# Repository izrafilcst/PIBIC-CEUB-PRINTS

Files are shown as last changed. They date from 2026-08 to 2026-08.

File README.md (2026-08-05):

# Tampa com encaixe para botões de arcade — PIBIC-CEUB

Modelagem de uma tampa em PETG com encaixe para dois botões de arcade,
derivada dos desenhos esquemáticos `botao-verde-desenho-esquematico.jpg` e
`botao-vermelho-desenho-esquematico.jpg`.

## Arquivos

| Arquivo | O que é |
|---|---|
| `desenho-tampa.svg` | Desenho técnico da tampa: distâncias entre botões, Ø dos furos, corte e **DETALHE B** do furo de fixação |
| `desenho-gabarito-passante.svg` | Desenho do gabarito de furo liso |
| `desenho-gabarito-roscado.svg` | Desenho do gabarito de rosca interna |
| `desenho-perfil-rosca.svg` | Perfil ISO 68-1 da M24 × 2 ampliado 18:1, com a memória de cálculo |
| `gabarito-passante.stl` | **Imprima primeiro.** 160 × 40 × 8 mm, 5 furos lisos |
| `gabarito-roscado.stl` | **Imprima junto.** 160 × 40 × 8 mm, 5 roscas M24 × 2 reais |
| `tampa-botoes.stl` / `.scad` | Tampa final, 209,30 × 108,50 × 4 mm, com os 2 furos M24 e os 6 furos de fixação rebaixados |
| `LISTA-DE-MATERIAIS.md` | **BOM completa** — botões, ferragens, fiação, solda, filamento, ferramentas |
| `desenho-caixa-painel.svg` | Painel dos botões do `.3mf` (Body1): 2 × Ø26, 9 × Ø10, círculos de furação |
| `desenho-caixa-corpo.svg` | Corpo do `.3mf` (Body2): parede, altura, 6 furos de inserto e o detalhe da interferência |
| `desenho-caixa-tampa.svg` | Tampa do `.3mf`: 6 furos rebaixados e detalhe 8:1 |
| `gerar_desenhos_3mf.py` | Gera os três acima **lendo a malha dos `.3mf`** — toda cota é medida, nenhuma digitada |
| `gerar_stl.py` | Gera os `.stl` (Python puro, sem dependências) |
| `gerar_desenhos.py` | Gera os `.svg` a partir das **mesmas** constantes de `gerar_stl.py` |
| `validar_stl.py` | Verifica estanqueidade, orientação, volume e perfil da rosca |

Os SVG abrem em qualquer navegador e estão em escala 1:1 em milímetros
(1 unidade SVG = 1 mm), então podem ser impressos em papel e medidos com régua.

> **Obsoletos:** `gabarito-tolerancia.scad` e `gabarito-tolerancia.stl` são da
> primeira versão (4 mm, 180 × 45). Foram substituídos pelo par
> passante/roscado de 8 mm. Pode apagar os dois — não imprima por engano.

---

## Cotas extraídas dos desenhos

### Botão verde — arcade 60 mm

| Cota | Valor (mm) |
|---|---|
| Rosca | M24 (P = 2) |
| Ø capa / bezel | 60,8 |
| Ø flange do corpo (apoia sobre o painel) | 37,7 |
| Espessura do flange | 4,4 |
| Altura acima do painel | 10,0 |
| Barril roscado abaixo do painel | 30,5 |
| Corpo do microswitch | 21,9 |
| Altura total | 62,4 |
| Anti-rotação | 2 × Ø3,3 |

**Verificação de consistência:** 10,0 + 30,5 + 21,9 = 62,4 ✔ — as cotas
fecham exatamente com a altura total, o que confirma a leitura do desenho.

### Botão vermelho — domo 100 mm

| Cota | Valor (mm) |
|---|---|
| Rosca | M24 × P2 |
| Ø domo externo | 98,5 |
| Ø anel interno | 87,8 |
| Altura acima do painel | 17,5 |
| Etapas do corpo | 6,5 / 21 / 10,5 / 3 |
| Anti-rotação | 2 × R3 |

### Consequência prática

Os dois botões usam **M24 × 2**, então o furo do painel é **idêntico** para
ambos — só muda o espaço livre ao redor. E o barril de 30,5 mm do verde
(o mais curto dos dois) deixa ~26 mm de rosca livre numa tampa de 4 mm,
folga mais que suficiente para a porca.

---

## Memória de cálculo

### 1. Distância entre os botões

`4 cm entre os botões` foi interpretado como **folga livre borda-a-borda**,
não centro-a-centro. Centro-a-centro de 40 mm é fisicamente impossível: só os
raios das capas somam 49,25 + 30,40 = **79,65 mm** — as capas se sobreporiam
em 39,65 mm antes mesmo de existir folga.

```
centro-a-centro = Ø_vermelho/2 + folga + Ø_verde/2
                = 98,5/2 + 40,00 + 60,8/2
                = 49,25  + 40,00 + 30,40
                = 119,65 mm
```

### 2. Tamanho da placa

```
largura = margem + Ø_verm/2 + 119,65 + Ø_verde/2 + margem
        = 5 + 49,25 + 119,65 + 30,40 + 5 = 209,30 mm
altura  = margem + Ø_verm + margem = 5 + 98,5 + 5 = 108,50 mm

x do furo vermelho = 5 + 49,25            =  54,25 mm
x do furo verde    = 54,25 + 119,65       = 173,90 mm
y de ambos         = 108,50 / 2           =  54,25 mm
```

`margem = 5` foi escolhida pela mesa da K1C: 209,30 numa mesa de 220 deixa
5,35 mm de cada lado em X — o suficiente para o skirt e para a sondagem de
nivelamento. Com `margem = 8` (o valor inicial) a peça ia a 215,30 e sobravam
2,35 mm por lado, o que não cabe. Acima de `margem = 7` o skirt não passa.

### 3. Perfil da rosca ISO 68-1 (M24 × 2)

Todos os valores vêm de duas constantes: `D = 24` e `P = 2`.

```
H  = P·√3/2 = 2 · 0,8660254 = 1,7320508 mm      (altura do triângulo gerador)
5H/8 = 1,0825318 mm                              (profundidade radial do filete)

D1 = D − 2·(5H/8) = 24 − 2,1650635 = 21,8349365 mm   → tabela ISO: 21,835 ✔
D2 = D − 0,649519·P = 24 − 1,299038 = 22,7009619 mm  → tabela ISO: 22,701 ✔
```

Decomposição de **um passo** ao longo do eixo, que é o que o gerador de malha
percorre:

```
plano da crista   P/4    = 0,500
flanco            5P/16  = 0,625
plano da raiz     P/8    = 0,250
flanco            5P/16  = 0,625
                  ─────────────
                  16P/16 = 2,000 = P   ✔ fecha exatamente
```

O comprimento axial do flanco sai do ângulo de 60° do perfil:

```
flanco = (5H/8) · tan30° = (5/8)·(P√3/2) · (1/√3) = 5P/16
```

Essa forma fechada importa: usando o literal arredondado `0,5412659·P` o
fechamento do passo errava por 2,6 × 10⁻⁸ mm e o teste de ângulo de flanco
falhava. Com `5P/16` o fechamento é exato em ponto flutuante binário
(P/4 + 5P/16 + P/8 + 5P/16 = P sem erro), e a validação passa.

No `desenho-perfil-rosca.svg` o triângulo gerador está desenhado com o **ápice
no meio do plano da crista**, a `H/4` além de D1, e os cantos da base a `H/8`
além de D — que é a truncagem da norma (`H − H/8 − H/4 = 5H/8`, batendo com
D1 = D − 2·5H/8). Por isso os flancos do triângulo caem exatamente sobre os
flancos do perfil.

### 4. Por que δ de 0,10 a 0,50

`δ` é a **folga radial** somada ao perfil ISO: desloca `Rmaj` e `Rmin` juntos
para fora, o que aumenta os dois diâmetros em `2δ` sem alterar o passo, o
ângulo de flanco nem a decomposição axial acima.

| δ | D maior | D1 menor | folga no Ø |
|---|---|---|---|
| 0,10 | 24,20 | 22,03 | +0,20 |
| 0,20 | 24,40 | 22,23 | +0,40 |
| 0,30 | 24,60 | 22,43 | +0,60 |
| 0,40 | 24,80 | 22,63 | +0,80 |
| 0,50 | 25,00 | 22,83 | +1,00 |

A faixa cobre de 0,20 a 1,00 mm no diâmetro porque é onde cai o erro típico de
FDM em PETG: 0,3–0,5 mm de fechamento por camada de parede, e uma rosca é
essencialmente uma sequência de paredes finas concêntricas, onde o efeito é
maior que num furo liso. Abaixo de δ = 0,10 a rosca sai travada; acima de
δ = 0,50 ela gira folgada e não segura o botão. O passo de 0,10 corresponde a
0,20 mm no diâmetro — abaixo disso a diferença some dentro da própria
variação da impressora e o teste deixa de discriminar.

### 5. Por que 8 mm de profundidade

```
8 mm ÷ P 2 mm = 4 passos completos de engate
```

Quatro filetes é o mínimo prático para que o teste signifique alguma coisa:

- com **1 ou 2 filetes** (o gabarito antigo de 4 mm) a rosca entra em quase
  qualquer folga, porque não há comprimento suficiente para o desalinhamento
  acumular. O teste passava mesmo com δ errado.
- com **4 filetes** o erro de passo acumulado ao longo do engate aparece, e a
  conicidade do furo — que na FDM sempre existe, porque as primeiras camadas
  saem mais largas — também.
- 8 mm também é o dobro da espessura da tampa (4 mm), então o gabarito é
  **mais severo** que a peça final. Se o botão passa no gabarito, passa na tampa.

Para o furo **passante** os mesmos 8 mm servem para revelar atrito real e
conicidade, que um furo de 4 mm mascara.

### 6. Tamanho e passo do gabarito

```
passo entre furos = 29 mm
material entre furos = 29 − 25,0 = 4,0 mm  (usando o maior Ø, 25,0)
largura = 4 × 29 + folga nas pontas = 160 mm
altura  = 40 mm  →  (40 − 25,0)/2 = 7,5 mm de material acima e abaixo
```

Os 4 mm entre furos são o mínimo para caberem 4 perímetros de 0,4 mm de cada
lado (4 × 0,4 × 2 = 3,2 mm) sem que as paredes se fundam. O chanfro 8 × 8 no
canto superior esquerdo marca o lado do **menor** furo/folga, para não
depender de contar da esquerda.

### 7. Compensação do furo da tampa

O PETG sai com **furo subdimensionado**. Duas causas somadas:

1. **Inchamento do extrudado** — o filamento expande ao sair do bico, e em
   curvas côncavas (parede interna de furo) esse material sobra para dentro.
2. **Contração térmica** — PETG encolhe ~0,3–0,5 % ao resfriar, e o furo
   encolhe junto.

O efeito líquido típico é 0,3 a 0,5 mm a menos que o diâmetro modelado, mas o
valor exato depende de impressora, bico, temperatura e fluxo. Daí o valor de
partida `24,7 = 24,0 + 0,7`, que é o meio da faixa dos furos passantes do
gabarito — **e é justamente o que o gabarito existe para substituir**.

---

## Layout

```
        209,30
 ┌─────────────────────────────────────────────────┐
 │      ___                                        │
 │    /     \                                      │   108,50
 │   | VERM  |          40,0        _____          │
 │   | Ø98,5 |<------- folga ---->/ VERDE \        │
 │    \ ___ /                     | Ø60,8 |        │
 │      ⊙ x=54,25                  \ _⊙_ /         │
 └─────────────────────────────────────────────────┘        x=173,90
        |<------------ 119,65 centro-a-centro ---->|

 Furos M24: (54,25 ; 54,25) e (173,90 ; 54,25) — Ø24,7
```

**Distâncias mínimas entre centros** (para as capas não colidirem):

| Par | Mínimo absoluto | Recomendado |
|---|---|---|
| verde ↔ verde | 60,8 | 65 |
| vermelho ↔ vermelho | 98,5 | 105 |
| verde ↔ vermelho | 79,65 | 82 |

---

## A caixa modelada no Fusion (`.3mf`)

Os dois `.3mf` do repositório são a peça real do projeto. **A geometria deles
não é a da tampa paramétrica** de `gerar_stl.py` — são projetos distintos, e o
do Fusion é o que vale.

| | `Projeto PIBIC-caixa.3mf` | `tampa.3mf` |
|---|---|---|
| Body1 — painel dos botões | 215 × 120 × 10, z 0–10 | |
| Body2 — corpo | 215 × 120 × 55, z 10–65 | |
| Body3 — tampa | | 215 × 120 × 4, z 65–69 |

Silhueta comum: retângulo 215 × 120 com **R55,00** nos quatro cantos (quase um
estádio — sobram só 10 mm de trecho reto nas laterais curtas). Caixa montada:
**69,00 mm** de altura.

`gerar_desenhos_3mf.py` corta a malha em planos Z, encadeia os segmentos em
contornos fechados e classifica cada um como círculo ou perfil. **Toda cota dos
três desenhos é medida na malha**, nenhuma foi digitada — então desenho e
modelo não podem divergir.

### O que a medição encontrou

**1. O parafuso M3 × 10 não cabe.** O furo do inserto no corpo tem **5,00 mm**
(z 60 a 65). Com tampa de 4,00 e rebaixo de 2,00:

```
penetração  = 10,00 − (4,00 − 2,00)          = 8,00 mm
necessário  =  8,00 + 1,00 de folga no fundo = 9,00 mm
interferência                                = 3,00 mm
```

O parafuso encosta no fundo antes de a cabeça assentar no rebaixo. Está
desenhado em escala 4:1 no DETALHE de `desenho-caixa-corpo.svg`. Corrigir para
**9,00 mm** de profundidade (a parede tem 55 mm de altura, espaço sobra) ou
usar **M3 × 6**.

**2. O furo de passagem da tampa é Ø4,20, não Ø3,40.** Ø4,20 é o diâmetro do
furo do *inserto* — parece o mesmo esboço reaproveitado nas duas peças. A
consequência é dimensional: a cabeça ISO 7380 (dk 5,7) passa a assentar numa
coroa de **0,75 mm** de largura em vez de 1,15 mm, e crava no PETG ao apertar.
A tampa também ganha 0,80 mm de folga lateral que não precisa ter.

**3. Furo dos botões Ø26,00** — você seguiu a especificação Adafruit, não os
24,70 calculados. É defensável (é o número do fabricante) e resolve de vez o
risco da aba anti-rotação. Em troca são 1,0 mm de folga radial: o botão é
centrado à mão e a porca M24 é quem cobre a folga — ela cobre com sobra.

**4. Folga entre as capas: 25,35 mm**, não os 40 mm do escopo inicial.

```
105,00 (entre centros) − 98,5/2 − 60,8/2 = 25,35 mm
```

Nada quebra por causa disso — as capas não se tocam e as duas cabem na placa.
Só registro que a cota mudou em relação ao que foi pedido no começo.

**5. O contorno interno tem R47,50 e não é offset uniforme do R55,00 externo.**
A parede varia de **9,87 a 11,06 mm** ao longo do perímetro. Nos seis furos de
inserto ela vale ~10, então **não afeta a fixação** — é só uma inconsistência
de esboço.

**6. Não há passagem de cabo** no modelo. O corpo é fechado nos quatro lados e
não tem recorte para o USB.

### Os 9 furos Ø10,00

Seis num círculo de furação **Ø63,00** (a 60°) em volta do botão de 100 mm e
três num **Ø42,00** (a 120°) em volta do de 60 mm. Todos caem **sob as capas**,
fora do flange do corpo do botão.

A posição é compatível com **LED Ø10 iluminando a capa por baixo**, o que
resolveria exatamente a queixa registrada na documentação da caixa — de que o
LED interno concentra o brilho no centro. Mas **a geometria não prova a
função**, então os LEDs entraram na lista de materiais como item pendente.

---

## Caixa, fechamento e fixação

Especificação vinda da documentação da caixa. Os botões são os **Adafruit
gigantes**: *Large Arcade Button* 60 mm (#1190 vermelho, #1192 branco, #1193
verde) e *Massive Arcade Button* 100 mm (#1185 vermelho, #1187 branco, #1188
verde). Os dois compartilham o mesmo bocal traseiro **M24**, o que confirma a
leitura dos JPG.

| Cota do fabricante | Valor | Situação neste projeto |
|---|---|---|
| Rosca traseira | M24 | ✔ bate com os desenhos |
| Espessura máx. do painel | 12,7 mm | ✔ tampa de 4 mm passa folgado |
| Furo de passagem recomendado | 26 mm | ⚠ ver abaixo |
| Microswitch | NO, LED opcional até 12 V | fora do escopo mecânico |

### ⚠ Conflito: furo de 26 mm × furo de 24,70 mm

A especificação diz "26 mm (1 polegada)" — 1" são 25,4 mm, então a própria
linha se contradiz. Mais importante: **26 mm é uma medida para painel de
MDF/acrílico furado com serra copo**, que só existe em medidas polegada e corta
com borda irregular. Em impressão 3D o furo é controlado em ±0,1 mm, e 26 mm
dariam **1,0 mm de folga radial** — o botão assenta descentrado e a cota de
119,65 mm centro-a-centro passa a ter ±1 mm de incerteza.

Existe porém **um cenário em que os 26 mm são obrigatórios**: se o elemento
anti-rotação for uma **aba no barril**, e não um pino sob o flange. Nesse caso
nada abaixo de 26 mm aceita o botão — e é a explicação mais provável para a
especificação folgada da Adafruit. É exatamente a medida que falta na
Pendência 1.

**Isso é decidível com o gabarito, sem paquímetro:** se o botão **não passar
nem no furo Ø25,00** (o último, no lado *sem* chanfro), há material além de
Ø24 no barril e o furo tem de ir para 26 mm. Se passar, vale o resultado normal
do gabarito em torno de 24,70. Ver passo 2-b da calibração.

### Fechamento: tampa parafusada com insertos por calor

6 pontos de fixação. Ferragens:

- 6 × parafuso **M3 × 10 ISO 7380** (cabeça abaulada, sextavado interno 2,0 mm)
- 6 × inserto roscado de latão M3, **Ø externo 4,6 mm × 5,0 mm**

| Feature | Onde | Ø | Profundidade |
|---|---|---|---|
| Furo do inserto | caixa (pilar) | 4,2 mm | **9,0 mm** (ver correção) |
| Ø externo do pilar | caixa | **≥ 10,0 mm** | altura ≥ 11,0 mm |
| Furo de passagem | tampa | 3,4 mm | passante |
| Rebaixo da cabeça | tampa | 6,5 mm | 2,0 mm |

### ⚠ Correção: profundidade do furo do inserto

A regra "comprimento do inserto + 1,0 mm" considera só o inserto, mas **o
parafuso é mais longo que ele**. Com rebaixo de 2,0 mm numa tampa de 4,0 mm, o
corpo do parafuso começa a 2,0 mm da superfície, não na face inferior:

```
penetração no pilar = L_parafuso − (esp_tampa − prof_rebaixo)
                    = L − (4,00 − 2,00)
                    = L − 2,00
```

| Parafuso | Penetra | Furo necessário | Furo pela regra antiga | Resultado |
|---|---|---|---|---|
| M3 × 8 | 6,00 | 7,00 | 6,00 | falta 1,00 mm |
| **M3 × 10** | **8,00** | **9,00** | **6,00** | **falta 3,00 mm** |
| M3 × 12 | 10,00 | 11,00 | 6,00 | falta 5,00 mm |

Nas três opções o parafuso **toca o fundo do furo antes de a cabeça assentar no
rebaixo**: a tampa não fecha, o aperto vira tração no pilar e o PETG racha na
base. Daí o furo de **9,0 mm** e o M3 × 10 fixado como padrão — dão 5,0 mm de
engate no latão (1,67 × D) mais 3,0 mm de PETG cru abaixo, que serve de reserva
se o inserto afundar demais na instalação.

Dois números que a especificação não trazia e que importam:

- **Ø externo do pilar ≥ 10,0 mm.** O inserto de 4,6 mm desloca material
  derretido para os lados; com menos de ~2,5 mm de parede o pilar abre. `4,6 +
  2 × 2,5 = 9,6 → 10`.
- **Sob o rebaixo sobram 2,0 mm de tampa** (`4,0 − 2,0`), e é a seção mais fina
  da peça, justamente onde entra a carga de aperto. Se o resultado ficar frágil,
  engrosse a tampa localmente para 6 mm nos 6 pontos em vez de aumentar o
  rebaixo.

> **Furo de 4,2 mm:** funciona, mas é o extremo folgado. Os insertos M3 mais
> comuns (Ruthex / CNC Kitchen, 4,6 × 5,0) especificam **4,0 mm**. Se o inserto
> girar depois de instalado, refaça com 4,0.

### Posição dos 6 pontos de fixação

A capa vermelha Ø98,5 centrada em `y = 54,25` ocupa de `y = 5,0` a `y = 103,5`
— **a altura inteira da tampa**. Não existe posição de parafuso ao lado dela.
Sobram 6 pontos, os 4 cantos mais os 2 meios das bordas longas:

| # | X | Y | folga até a capa mais próxima |
|---|---|---|---|
| P1 | 8,00 | 8,00 | 12,91 (vermelho) |
| P2 | 104,65 | 8,00 | 15,90 (vermelho) |
| P3 | 201,30 | 8,00 | 20,11 (verde) |
| P4 | 8,00 | 100,50 | 12,91 (vermelho) |
| P5 | 104,65 | 100,50 | 15,90 (vermelho) |
| P6 | 201,30 | 100,50 | 20,11 (verde) |

Critério: distância do centro do parafuso ao centro do botão ≥ `raio da capa +
3,25` (metade do rebaixo Ø6,5). Com 8,00 mm de recuo das bordas sobram 4,75 mm
de PETG maciço entre o rebaixo e a borda da placa.

**Limitação conhecida:** os vãos ficam em 96,65 mm em X e **92,50 mm em Y sem
nenhum apoio intermediário**. Numa tampa de 4 mm que recebe impacto, a região
central das bordas curtas vai fletir.

Cheguei a considerar **aumentar a altura da placa** para abrir espaço de
parafuso ao lado do botão vermelho, e **as contas não sustentam a ideia**:

- para o rebaixo Ø6,5 caber entre a borda da capa e a borda da placa **com
  acesso para a chave allen** (folga de 5 mm), a altura teria de ir a
  **131 mm**, não os ~122 que eu tinha estimado;
- e ao crescer a placa **os parafusos de canto se afastam** do botão vermelho.
  Hoje os quatro apoios mais próximos estão a 65,4 / 68,4 mm. Com 131 mm
  ficariam a 57,0 / 73,4 mm — dois melhoram, dois pioram.

O ganho líquido é quase nulo para 20 % a mais de material e de tempo de
impressão. **A placa fica em 209,30 × 108,50.**

Se a rigidez ainda incomodar depois de montado, o caminho eficaz **não é mais
parafuso, é mais seção**: a rigidez à flexão cresce com `t³`. Passar a tampa de
4 para 6 mm multiplica a rigidez por `6³/4³ = 3,4` sem mexer em layout nenhum,
e o botão aceita painel de até 12,7 mm. O custo é 50 % mais material e recalcular
a profundidade do furo do inserto (`10 − (6 − 2) + 1 = 7,0 mm`).

---

## Modelando no Autodesk Fusion

Todos os números abaixo estão nos SVG; esta seção é só o roteiro.

### Tampa (`desenho-tampa.svg`)

1. Esboço no plano XY: retângulo `209,30 × 108,50` com o canto em (0, 0).
2. Dois círculos de **Ø24,70** (ajuste depois do gabarito) em
   `(54,25 ; 54,25)` e `(173,90 ; 54,25)`.
3. **Extrude 4 mm**, operação *New Body*. Os círculos como *Cut* ou já
   deixados como ilhas no perfil.
4. Opcional: `Chamfer 0,4 mm` na boca superior dos furos — ajuda o barril a
   entrar e disfarça o "elephant's foot" da primeira camada.

5. **Fixação, 6 pontos.** Use `Create ▸ Hole` com tipo *Counterbore*, em vez de
   dois esboços — o Fusion mantém as duas medidas ligadas:
   - Ø do furo `3,4 mm`, passante (*Through All*)
   - Ø do rebaixo `6,5 mm`, profundidade `2,0 mm`
   - posições `(8 ; 8)`, `(104,65 ; 8)`, `(201,30 ; 8)`, `(8 ; 100,5)`,
     `(104,65 ; 100,5)`, `(201,30 ; 100,5)`

   O rebaixo vai na face **de cima** (a que fica à mão). Confira que restaram
   2,0 mm de material sob cada rebaixo antes de extrudar.

Não modele rosca na tampa: com 4 mm você teria 2 filetes, insuficiente. O
botão é preso pela porca dele, com a tampa apenas como painel.

### Pilares de inserto na caixa

Um pilar em cada uma das 6 coordenadas acima, medidas a partir do **mesmo
canto** que a tampa (senão espelha):

1. Círculo Ø`10,0` na face interna do fundo, `Extrude` até `≥ 11,0 mm` de
   altura, *Join*.
2. `Create ▸ Hole` simples, Ø`4,2 mm`, profundidade **`9,0 mm`**, a partir do
   topo do pilar. Não use *Through All*.
3. `Fillet 2 mm` na base do pilar contra a parede/fundo — é onde a carga de
   aperto concentra e o PETG é sensível a entalhe.

Imprima o pilar **na vertical, junto com a caixa**, para que as camadas fiquem
perpendiculares ao eixo do parafuso.

### Gabarito passante (`desenho-gabarito-passante.svg`)

1. Retângulo `160 × 40`, chanfro `8 × 8` no canto superior esquerdo.
2. Cinco círculos em `y = 20`, `x = 22 / 51 / 80 / 109 / 138`.
3. Diâmetros, nessa ordem: `24,40 / 24,60 / 24,70 / 24,80 / 25,00`.
4. **Extrude 8 mm.**

### Gabarito roscado (`desenho-gabarito-roscado.svg`)

Mesma placa; os furos viram rosca. No Fusion:

1. Furo liso de Ø igual ao **D1** da coluna, extrudado 8 mm.
2. `Create ▸ Thread`, marcar **Modeled** (senão a rosca é só cosmética e não
   sai no STL), tipo `ISO Metric profile`, tamanho `24 mm`, designação
   `M24x2`, classe qualquer, **Internal**.
3. O Fusion não aceita δ diretamente. Duas saídas:
   - **Offset:** aplique a rosca M24 × 2 padrão e depois `Modify ▸ Offset
     Face` de `+δ` na face da rosca (0,10 / 0,20 / 0,30 / 0,40 / 0,50).
   - **Ou** edite `ISO Metric profile.xml` na biblioteca de roscas do Fusion
     e adicione as cinco classes. Mais trabalhoso, mas fica reutilizável.

Diâmetros por coluna (esquerda → direita):

| # | δ | D maior | D1 menor |
|---|---|---|---|
| 1 | 0,10 | 24,20 | 22,03 |
| 2 | 0,20 | 24,40 | 22,23 |
| 3 | 0,30 | 24,60 | 22,43 |
| 4 | 0,40 | 24,80 | 22,63 |
| 5 | 0,50 | 25,00 | 22,83 |

Se preferir não brigar com a biblioteca de roscas, **imprima direto os STL
prontos** (`gabarito-passante.stl` e `gabarito-roscado.stl`) e modele no
Fusion só a tampa final. Os STL já estão validados.

---

## Procedimento de calibração

1. **Imprima os dois gabaritos** (~32 e ~34 cm³) com **exatamente** os
   parâmetros que usará na tampa final — bico, altura de camada, temperatura,
   fluxo e velocidade. Trocar qualquer um invalida o teste.

2. **Passante:** teste o barril M24 dos dois botões em cada furo, do menor
   para o maior. O canto chanfrado marca o furo #1 (Ø24,40). O furo bom é o
   **primeiro em que o botão entra com leve pressão dos dedos**, sem folga
   lateral perceptível e sem forçar.

2-b. **Teste do Ø25,00 — decide os 26 mm da Adafruit.** Se o botão **não
   passar nem no último furo** (Ø25,00, lado sem chanfro), existe material
   além de Ø24 no barril — quase certamente a aba anti-rotação. Nesse caso
   abandone o 24,70 e use **26,00 mm**, como a Adafruit especifica, e meça a
   aba com paquímetro para confirmar. Se passar, siga com o resultado do
   passo 2.

3. **Roscado:** parafuse o botão em cada furo. O δ bom é o **menor em que o
   botão rosqueia até o fim sem ferramenta e sem raspar**. Este resultado só
   é necessário se você quiser depois uma peça com rosca integrada — para a
   tampa de 4 mm, o resultado que importa é o do passante.

4. **Ajuste `folga_m24`** com o valor do passante:
   - em `tampa-botoes.scad`, linha do parâmetro `folga_m24`
   - ou em `gerar_stl.py`, função `tampa()`, e rode `python gerar_stl.py`
   - ou direto no esboço do Fusion

5. **Imprima a tampa.**

### Parâmetros de impressão — PETG na Creality K1C

A K1C é uma CoreXY rápida e fechada, com bico de aço endurecido e ventoinha
auxiliar potente. Os perfis de fábrica são otimizados para **velocidade**, não
para precisão dimensional — e este projeto depende de precisão num furo.

| Parâmetro | Valor | Por quê |
|---|---|---|
| Bico / camada | 0,4 mm / 0,2 mm | padrão |
| Temperatura bico | **245–250 °C** | o bico de aço endurecido da K1C conduz pior que latão; +5 a 10 °C |
| Mesa | **70 °C** (não mais) | ver aviso da placa PEI abaixo |
| Perímetros | **4** | define diretamente a parede do furo |
| Preenchimento | **30 % giroide** | giroide é isotrópico — a caixa recebe impacto de todas as direções |
| **Velocidade parede externa** | **30–40 mm/s** | o padrão da K1C (>150 mm/s) distorce o furo |
| **Aceleração** | **≤ 5000 mm/s²** | o padrão (20000) faz cantos e furos incharem |
| **Ventoinha auxiliar** | **0–20 %** | a lateral da K1C é forte demais e delamina PETG |
| Ventoinha do modelo | 30–50 % | PETG precisa de bem menos que PLA |
| Suportes | não | peças planas |

**Avisos específicos da K1C:**

- **Placa PEI + PETG grudam quimicamente.** É o risco prático real aqui: o
  PETG pode arrancar lascas do PEI. Passe **bastão de cola como agente de
  soltura** (não de adesão) e **espere a placa esfriar totalmente** antes de
  remover a peça. Manter a mesa em 70 °C em vez de 85 °C também ajuda muito.
- **Câmara fechada:** deixe a tampa superior entreaberta. O PETG não precisa
  de câmara quente e a K1C passa fácil de 50 °C em peças grandes.
- **Calibre fluxo e pressure advance antes do gabarito.** Numa impressora
  rápida, fluxo descalibrado é a maior fonte de erro no diâmetro do furo. O
  Orca Slicer tem perfil de K1C e a suíte de calibração pronta — recomendo em
  vez do Creality Print por isso.
- **Use o mesmo perfil nas duas impressões.** Se o gabarito sair no modo
  rápido e a tampa no modo padrão, o resultado do teste não vale.

### Instalação dos insertos de latão

Ferro de solda a **220–240 °C** (abaixo disso o PETG não flui; acima ele
degrada e solta fumo).

1. Apoie o inserto reto sobre o furo de 4,2 mm, sem forçar.
2. Encoste a ponta do ferro no latão **sem fazer pressão** — quem afunda o
   inserto é o calor conduzido, não a força. Pressionar entorta o eixo.
3. Deixe descer até ficar rente à face do pilar, ou **0,5 mm abaixo** dela.
   Nunca acima: um inserto saliente impede a tampa de assentar.
4. Retire o ferro e encoste uma superfície metálica plana sobre o topo
   enquanto o PETG esfria — é isso que garante a rosca ortogonal.

Faça um pilar de teste avulso antes dos 6 definitivos. Se o inserto girar sob
torque depois de frio, o furo está grande: refaça com 4,0 mm.

> **Mesa:** a tampa tem 209,30 × 108,50 mm. Na K1C (220 × 220) sobram ~5,3 mm
> de cada lado em X — o suficiente para o skirt e para a sondagem do
> nivelamento. Se quiser mais borda, aumente `margem`, mas não passe de 7.

---

## Pendências — preciso de duas medidas suas

1. **Posição dos furos anti-rotação.** Os desenhos dão o diâmetro
   (2 × Ø3,3 no verde, 2 × R3 no vermelho) mas **não cotam a distância do
   eixo da rosca até o centro desses elementos**. Por isso eles foram
   **deliberadamente omitidos** do modelo.

   Na prática isso raramente incomoda: as duas capas são circulares e
   simétricas, então a rotação não afeta a aparência, e uma porca bem apertada
   segura o botão. Se ainda assim quiser os furos, meça com paquímetro a
   distância **centro da rosca → centro do pino** e me passe.

   **Ganhou peso** depois da especificação Adafruit: se o anti-rotação for uma
   aba *no barril* em vez de um pino sob o flange, ele muda o furo principal de
   24,70 para 26,00 mm. O passo 2-b da calibração resolve isso sem paquímetro.

2. **Comprimento roscado útil do botão vermelho.** As cotas 6,5 / 21 / 10,5 / 3
   do corpo estão em fonte pequena no JPG e não deixam claro qual trecho é
   rosca. Isso não afeta a tampa de 4 mm com porca, mas **limita a espessura
   máxima de uma tampa roscada**, caso você opte por essa via depois do
   gabarito roscado. Meça o comprimento da rosca com paquímetro antes de
   decidir.

---

## Nota técnica sobre a geração das malhas

`gerar_stl.py` não usa biblioteca de CAD. A face da placa é dividida em faixas
convexas com um furo cada; o círculo e o contorno da faixa são costurados por
caminhamento angular, sem inventar vértices no contorno. Isso faz faixas
vizinhas compartilharem exatamente os mesmos vértices na linha de corte, o que
elimina junções-T. As paredes são levantadas só das arestas que pertencem a uma
única faixa.

A rosca é gerada como campo de altura sobre o cilindro: o raio em (θ, z)
depende só da fase `(z − P·θ/2π) mod P`, então a parede helicoidal é malhável
numa grade (θ, z) e as colunas são amostradas exatamente nas quebras do perfil.

`validar_stl.py` confere tudo. Resultado atual:

```
gabarito-passante.stl   160 x 40 x 8 mm    2796 triangulos   31,784 cm3  (0,0000 % divergencia)
gabarito-roscado.stl    160 x 40 x 8 mm   21816 triangulos   33,753 cm3  (0,0005 % divergencia)
tampa-botoes.stl     209,30 x 108,50 x 4   7824 triangulos   86,497 cm3  (0,0000 % divergencia)

arestas nao pareadas: 0    arestas mal orientadas: 0
ISO: H 1,7321 | D1 21,8349 (tabela 21,835) | D2 22,7010 | D 24,0000 | soma axial = passo  OK
raios e fase das cristas: OK para delta 0,10 ... 0,50
rebaixos M3 (6x): topo D6,500 | base D3,400 | fundo z=2,000   OK
```

Os furos rebaixados obrigaram duas extensões no gerador. A placa da tampa
deixou de ser uma fita por furo e virou uma **grade 5 × 3** com no máximo um
furo por célula — as linhas de corte caem no meio dos vãos medidos de **borda a
borda** das features, não de centro a centro, senão a boca de um furo cruzaria
o corte. Sete das quinze células ficam sem furo nenhum e são trianguladas por
leque **a partir do centroide**: um leque a partir de um canto geraria
triângulos degenerados sobre os pontos colineares que `subdividir()` insere nas
arestas longas. E o furo rebaixado virou três superfícies (cilindro do rebaixo,
coroa plana do fundo, cilindro de passagem) em vez de uma.

O volume de malha é comparado com um cálculo analítico independente (área do
polígono regular inscrito e área da seção helicoidal, ambas fechadas), e não
com outra medição da mesma malha — senão o teste não provaria nada.

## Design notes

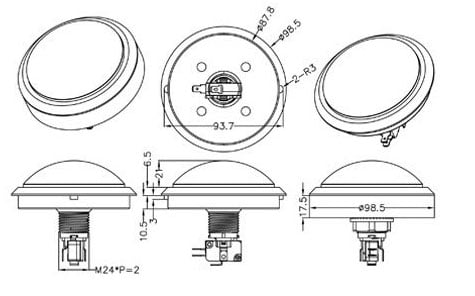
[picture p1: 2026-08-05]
botao-vermelho-desenho-esquematico.jpg

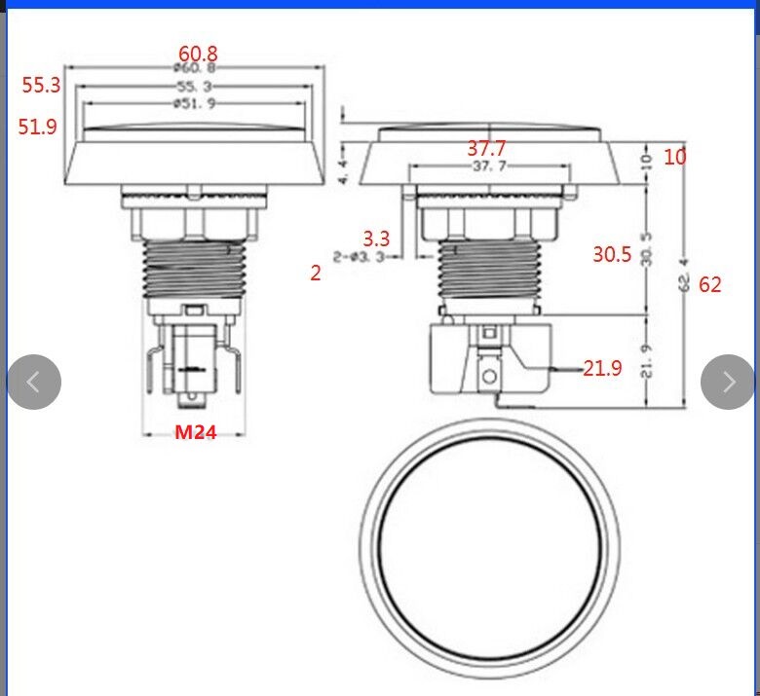
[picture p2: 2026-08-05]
botao-verde-desenho-esquematico.jpg

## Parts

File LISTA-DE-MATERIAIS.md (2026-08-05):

# Lista de materiais — PIBIC-CEUB

Levantada a partir da geometria real dos `.3mf` do repositório (215 × 120 mm,
6 pontos de fixação M3, 2 furos Ø26, 9 furos Ø10) e da documentação da caixa.

Legenda da coluna **Status**:

| | |
|---|---|
| ✅ | definido, pode comprar |
| ⚠️ | precisa de uma confirmação sua antes de comprar |
| ❓ | depende de decisão de projeto ainda não tomada |

---

## 1. Botões

| Qtd | Item | Status | Observação |
|---|---|---|---|
| 1 | Adafruit **Massive Arcade Button 100 mm** — #1185 verm. / #1187 branco / #1188 verde | ✅ | vai no furo Ø26 em (65 ; 60) |
| 1 | Adafruit **Large Arcade Button 60 mm** — #1190 verm. / #1192 branco / #1193 verde | ✅ | vai no furo Ø26 em (170 ; 60) |
| 2 | Microswitch de arcade NO, sobressalente | ✅ | é a peça que morre primeiro num controle de impacto |

> **Não compre porca M24.** Ela vem com o botão, junto com o microswitch e o
> LED interno com resistor embutido. Comprar avulso é desperdício — e porca
> M24 avulsa é cara e difícil de achar no diâmetro/passo certo.

---

## 2. Fixação da tampa (6 pontos)

**Decidido: M3 × 6, mantendo o modelo como está.**

| Qtd | Item | Status | Observação |
|---|---|---|---|
| 6 | Parafuso **M3 × 6 ISO 7380**, cabeça abaulada, sextavado interno 2,0 mm | ✅ | |
| 6 | **Inserto roscado de latão M3**, Ø externo 4,6 × **4,0** mm | ✅ | 4,0 e não 5,0 — ver abaixo |
| — | *alternativa sem inserto:* 6 × porca M3 DIN 934 em bolso sextavado | ❓ | 5,5 mm entre faces × 2,4 de espessura; exige redesenhar o pilar |

Confere com o furo de **5,00 mm** já modelado (z 60 a 65):

```
penetração = 6,00 − (4,00 − 2,00) = 4,00 mm
folga no fundo = 5,00 − 4,00      = 1,00 mm   ✔
```

> **Peça o inserto de 4,0 mm, não o de 5,0.** Um inserto de 5,0 num furo de
> 5,00 não deixa vazio nenhum embaixo, e o PETG derretido na instalação não
> tem para onde ir — ele sobe em volta e empurra o inserto para fora, o que
> impede a tampa de assentar. Com 4,0 sobra 1,00 mm de folga no fundo, e o
> M3 × 6 penetra exatamente os 4,0 mm do latão.
>
> Se só achar o de 5,0 mm, dá para usar: aprofunde o furo para 6,00 mm no
> Fusion antes de imprimir.

---

## 3. Fiação e solda

| Qtd | Item | Status | Observação |
|---|---|---|---|
| 1 | **Estanho 60/40 com fluxo, Ø0,8 mm** — rolo de 100 g | ✅ | 0,8 mm é o diâmetro certo para eletrônica; 1,0 mm já é grosso demais para LED |
| 1 | **Fluxo** em pasta ou caneta | ✅ | o do estanho não basta para faston e fio estanhado |
| 3 m | **Cabo flexível estanhado 22 AWG** (0,33 mm²), 2 cores | ✅ | sinal dos microswitches |
| 2 m | **Cabo flexível estanhado 20 AWG** (0,5 mm²), 2 cores | ❓ | só se houver LEDs externos — ver seção 4 |
| 4 | **Terminal faston fêmea pré-isolado 4,8 mm** (0,187") | ⚠️ | 2 por botão (COM + NO). **Meça o terminal do switch antes** — parte dos microswitches de arcade usa 2,8 mm. Compre 10: crimpagem estraga um ou dois |
| 1 | Espaguete termorretrátil, sortido Ø2 e Ø3 mm | ✅ | |
| 1 | Conector destacável (JST-XH ou Dupont) entre tampa e painel | ✅ | sem isso você solda e dessolda toda vez que abrir a caixa |
| 1 | Malha dessoldadora ou sugador | ✅ | |

---

## 4. Iluminação — os 9 furos Ø10

❓ **Item inteiro pendente de confirmação.** O modelo tem **9 furos Ø10,00
passantes** no painel: 6 num círculo de furação Ø63 em volta do botão de
100 mm e 3 num Ø42 em volta do de 60 mm. Eles caem **sob as capas**, fora do
flange do corpo do botão.

A posição é compatível com **LED Ø10 mm iluminando a capa por baixo** — e isso
resolveria justamente a queixa da sua documentação, de que o LED interno
"concentra o brilho no centro devido à profundidade da carcaça". Mas **a
geometria não prova a função**. Se for isso:

| Qtd | Item | Observação |
|---|---|---|
| 9 | LED Ø10 mm difuso | cor à sua escolha |
| 9 | Suporte/aro plástico para LED Ø10 | opcional, melhora o acabamento no furo |
| 9 | Resistor limitador | valor depende da tensão de alimentação e do Vf do LED |

Se **não** for iluminação, me diga o que são e eu recoto o desenho.

---

## 5. Eletrônica de controle

❓ **Ainda não há decisão registrada no projeto.** Duas rotas usuais:

| Item | Quando escolher |
|---|---|
| **Arduino Pro Micro** (ATmega32U4) | vira joystick/teclado USB nativo, sem driver — rota mais curta |
| **Raspberry Pi Pico** | mais I/O e mais barato, mas exige firmware HID |

Em qualquer uma: 1 × cabo USB e 1 × passa-cabo ou recorte na caixa (**não
existe no modelo atual** — o corpo é fechado nos 4 lados).

---

## 6. Consumíveis de impressão

| Qtd | Item | Status |
|---|---|---|
| 1 kg | **Filamento PETG** | ✅ |
| 1 | Bastão de cola escolar | ✅ agente de **soltura** no PEI, não de adesão |
| 1 | Álcool isopropílico | ✅ |

**Estimativa de filamento**, dos volumes reais das malhas:

```
painel (Body1)   214,37 cm3
corpo  (Body2)   309,04 cm3
tampa  (Body3)    92,22 cm3
                 ──────────
sólido           615,63 cm3
```

A 4 perímetros e 30 % de preenchimento giroide, a densidade efetiva fica em
torno de 50 % → **≈ 308 cm³ ≈ 391 g**. Some refugo e uma peça refeita:
**compre 1 kg**.

---

## 7. Ferramentas

| Item | Para quê | Status |
|---|---|---|
| **Ferro de solda com controle de temperatura** | 220–240 °C para os insertos; sem controle você queima o PETG | ✅ |
| Ponta cônica dedicada aos insertos | latão sujo estraga a ponta de eletrônica | ✅ |
| Chave allen 2,0 mm | cabeça dos M3 ISO 7380 | ✅ |
| **Paquímetro** | resolve as duas pendências abertas do projeto | ✅ |
| Alicate de crimpar faston | crimpar torto é o defeito nº 1 em fiação de arcade | ✅ |
| Pistola de cola quente | alívio de tração dos fios e anti-rotação dos botões | ✅ |

---

## O que trava a compra agora

1. **Largura do terminal do microswitch** — 4,8 mm ou 2,8 mm. Define o faston.
2. **Função dos 9 furos Ø10** — define se entram LEDs, suportes e resistores.
3. **Microcontrolador** — define cabo, conector e recorte de saída na caixa.

~~Profundidade do furo do inserto~~ — **resolvido: M3 × 6**, modelo mantido.

Os itens ✅ podem ser comprados hoje sem risco de sobrar.

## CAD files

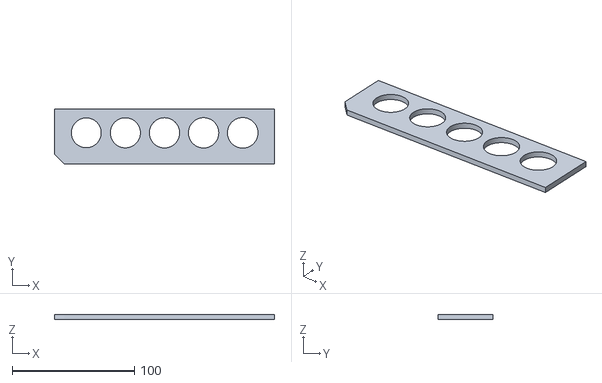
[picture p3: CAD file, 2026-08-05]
gabarito-tolerancia.stl
180.0 x 45.0 x 4.00

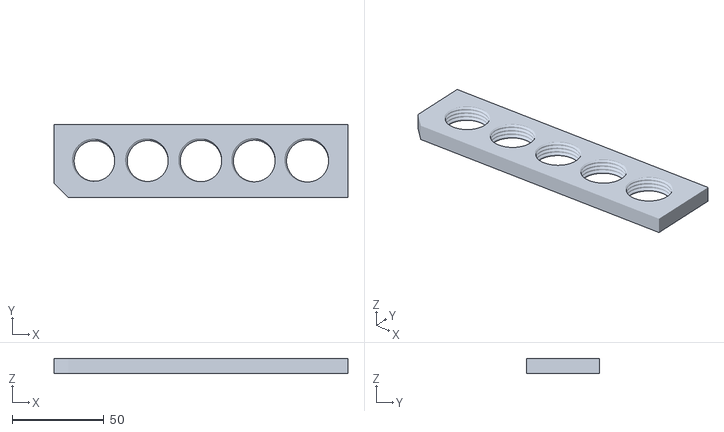
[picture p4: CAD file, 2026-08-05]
gabarito-roscado.stl
160.0 x 40.0 x 8.00

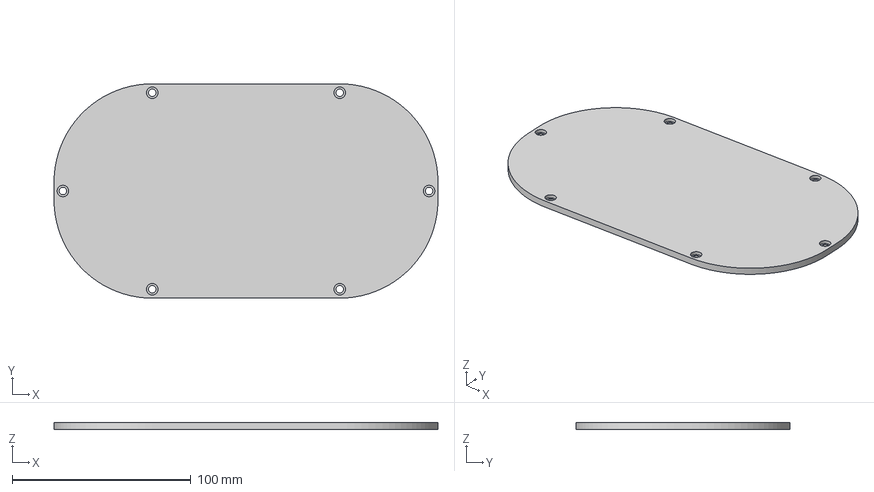
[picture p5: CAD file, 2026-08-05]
tampa.3mf
215.0 x 120.0 x 4.00 mm

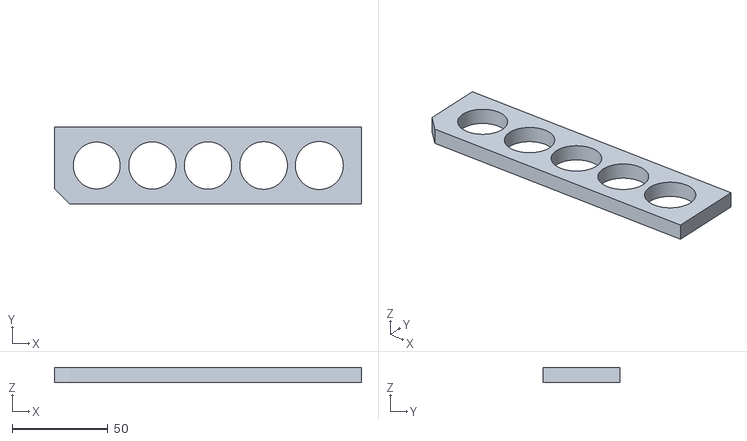
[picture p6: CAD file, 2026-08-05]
gabarito-passante.stl
160.0 x 40.0 x 8.00

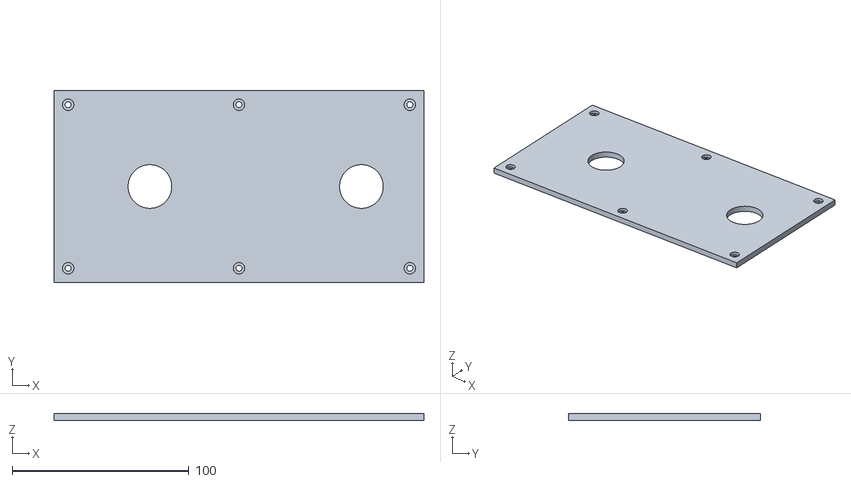
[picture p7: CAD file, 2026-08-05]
tampa-botoes.stl
209.3 x 108.5 x 4.00

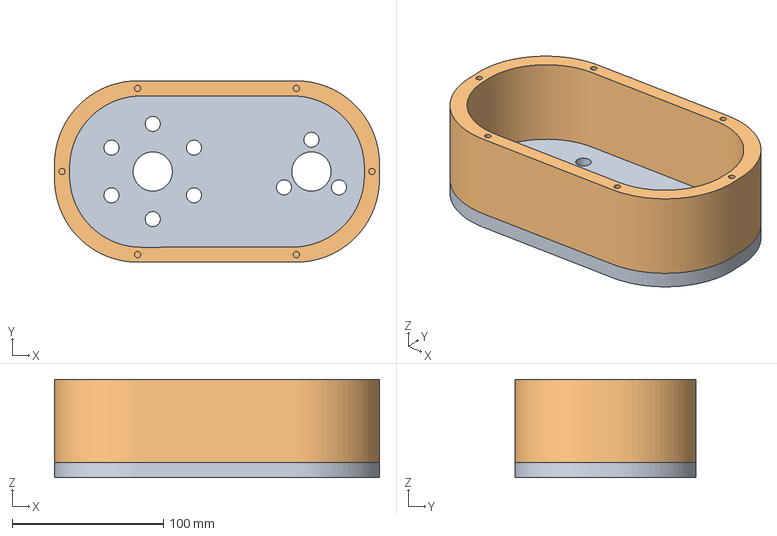
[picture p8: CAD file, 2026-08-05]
Projeto PIBIC-caixa.3mf
215.0 x 120.0 x 65.0 mm

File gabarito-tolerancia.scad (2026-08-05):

// =====================================================================
// GABARITO DE TOLERANCIA - furo M24 para botoes de arcade em PETG
// PIBIC-CEUB
//
// Objetivo: descobrir empiricamente qual diametro modelado produz o
// encaixe correto da rosca M24 dos dois botoes, compensando a
// contracao do PETG e a sobreposicao de extrusao da sua impressora.
//
// COMO USAR:
//   1. Imprima com EXATAMENTE os mesmos parametros que usara na tampa
//      final (bico, altura de camada, temperatura, fluxo, velocidade).
//   2. Teste a rosca de cada botao em cada furo, do menor para o maior.
//   3. O furo bom e o primeiro em que o botao entra com leve pressao
//      dos dedos, sem folga lateral e sem forcar.
//   4. Anote o valor e use em tampa-botoes.scad (parametro folga_m24).
//
// O canto chanfrado marca o furo #1 (o MENOR).
// =====================================================================

// ---------------------- PARAMETROS ----------------------------------

espessura   = 4;                                    // mm - igual ao da tampa final
diametros   = [24.4, 24.6, 24.7, 24.8, 25.0];       // mm - diametros a testar
passo       = 32;                                   // mm - distancia entre centros
largura     = 180;                                  // mm
altura      = 45;                                   // mm
chanfro     = 8;                                    // mm - marca o inicio da sequencia

gravar_texto     = true;   // grava o diametro ao lado de cada furo
prof_gravacao    = 0.6;    // mm
tam_texto        = 5;      // mm

$fn = 128;                 // resolucao dos circulos (nao reduzir: afeta o diametro real)

// ---------------------- CONSTRUCAO ----------------------------------

n   = len(diametros);
x0  = largura/2 - (n-1)*passo/2;   // x do primeiro furo
yc  = altura/2 + 3;                // furos levemente acima do centro (espaco p/ texto)

module placa() {
    linear_extrude(espessura)
        polygon([
            [chanfro, 0],
            [largura, 0],
            [largura, altura],
            [0,       altura],
            [0,       chanfro]
        ]);
}

module furos() {
    for (i = [0 : n-1])
        translate([x0 + i*passo, yc, -1])
            cylinder(h = espessura + 2, d = diametros[i]);
}

module rotulos() {
    for (i = [0 : n-1])
        translate([x0 + i*passo, 6, espessura - prof_gravacao])
            linear_extrude(prof_gravacao + 1)
                text(str(diametros[i]),
                     size = tam_texto,
                     halign = "center",
                     valign = "center",
                     font = "Liberation Sans:style=Bold");
}

difference() {
    placa();
    furos();
    if (gravar_texto) rotulos();
}

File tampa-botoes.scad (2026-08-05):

// =====================================================================
// TAMPA COM ENCAIXE PARA BOTOES DE ARCADE - PIBIC-CEUB
//
// Botao VERMELHO (domo 98,5 mm) a esquerda
// Botao VERDE   (arcade 60,8 mm) a direita
// Folga livre entre as bordas das capas: 40 mm
//
// Ambos os botoes usam rosca M24 x P2, portanto o furo do painel e
// IDENTICO para os dois. O que muda e apenas o espaco livre ao redor.
//
// ANTES DE IMPRIMIR: rode o gabarito-tolerancia.scad e ajuste
// 'folga_m24' abaixo com o valor que encaixou.
// =====================================================================

// ---------------------- COTAS DOS BOTOES (dos desenhos) --------------
// Botao vermelho (domo 100 mm)
BV_cap_d      = 98.5;   // diametro externo do domo
BV_anel_d     = 87.8;   // anel interno
BV_altura     = 17.5;   // altura acima do painel

// Botao verde (arcade 60 mm)
BG_cap_d      = 60.8;   // diametro externo da capa/bezel
BG_flange_d   = 37.7;   // flange do corpo que APOIA sobre o painel
BG_flange_h   = 4.4;    // espessura desse flange
BG_altura     = 10.0;   // altura acima do painel
BG_barril     = 30.5;   // comprimento abaixo do painel
BG_total      = 62.4;   // altura total do conjunto

// Rosca comum aos dois
ROSCA_d       = 24.0;   // M24 nominal

// ---------------------- FIXACAO DA TAMPA -----------------------------
// 6x parafuso M3 x 10 ISO 7380 (cabeca abaulada, dk 5,7 / k 1,65) em
// inserto de latao M3 (D ext 4,6 x 5,0) instalado a quente na caixa.
PARAF_d_pass  = 3.4;    // ISO 273 media para M3
PARAF_d_reb   = 6.5;    // rebaixo: folga sobre dk 5,7 + entrada da chave
PARAF_h_reb   = 2.0;    // > k 1,65, entao a cabeca fica submersa
PARAF_recuo   = 8.0;    // do centro do parafuso ate a borda da placa

// ---------------------- PARAMETROS AJUSTAVEIS ------------------------

folga_m24     = 24.7;   // <<< AJUSTE COM O RESULTADO DO GABARITO
folga_borda   = 40;     // mm - espaco livre entre as bordas das capas
espessura     = 4;      // mm - espessura da tampa
margem        = 5;      // mm - borda de material ao redor das capas
                        //      5 => placa 209,3 x 108,5, cabe na Creality K1C
                        //      (220x220) com ~5,3 mm de folga por lado

mostrar_botoes   = false;  // preview dos botoes montados (nao exporta)
gravar_contorno  = false;  // grava o contorno das capas na face superior
prof_gravacao    = 0.4;

$fn = 128;              // NAO reduzir: afeta o diametro real dos furos

// ---------------------- GEOMETRIA DERIVADA ---------------------------

// Centro-a-centro = soma dos raios das capas + folga livre desejada
dist_centros = BV_cap_d/2 + BG_cap_d/2 + folga_borda;   // = 119.65

largura = BV_cap_d/2 + dist_centros + BG_cap_d/2 + 2*margem;
altura  = BV_cap_d + 2*margem;

cx_vermelho = margem + BV_cap_d/2;
cx_verde    = cx_vermelho + dist_centros;
cy          = altura/2;

// Os 6 parafusos: cantos + meio das bordas longas. Nao ha posicao possivel
// ao lado do botao vermelho: a capa de 98,5 ocupa de y=5 a y=103,5, ou seja,
// toda a altura util da placa.
xs_paraf = [PARAF_recuo, largura/2, largura - PARAF_recuo];
ys_paraf = [PARAF_recuo, altura  - PARAF_recuo];

echo(str("Distancia entre centros: ", dist_centros, " mm"));
echo(str("Placa: ", largura, " x ", altura, " x ", espessura, " mm"));
echo(str("Material sob a cabeca do parafuso: ", espessura - PARAF_h_reb, " mm"));
// Profundidade que o furo do inserto precisa ter na CAIXA (peca separada):
echo(str("Furo do inserto na caixa: D", 4.2, " x ",
         10 - (espessura - PARAF_h_reb) + 1, " mm de profundidade"));

// ---------------------- CONSTRUCAO -----------------------------------

module tampa() {
    difference() {
        cube([largura, altura, espessura]);

        // furo da rosca M24 - botao vermelho
        translate([cx_vermelho, cy, -1])
            cylinder(h = espessura + 2, d = folga_m24);

        // furo da rosca M24 - botao verde
        translate([cx_verde, cy, -1])
            cylinder(h = espessura + 2, d = folga_m24);

        // 6x furo de fixacao com rebaixo para a cabeca abaulada.
        // O rebaixo abre na face de CIMA (z = espessura).
        for (px = xs_paraf, py = ys_paraf) {
            translate([px, py, -1])
                cylinder(h = espessura + 2, d = PARAF_d_pass);
            translate([px, py, espessura - PARAF_h_reb])
                cylinder(h = PARAF_h_reb + 1, d = PARAF_d_reb);
        }

        if (gravar_contorno) {
            translate([cx_vermelho, cy, espessura - prof_gravacao])
                difference() {
                    cylinder(h = prof_gravacao + 1, d = BV_cap_d);
                    translate([0,0,-1])
                        cylinder(h = prof_gravacao + 3, d = BV_cap_d - 1.2);
                }
            translate([cx_verde, cy, espessura - prof_gravacao])
                difference() {
                    cylinder(h = prof_gravacao + 1, d = BG_cap_d);
                    translate([0,0,-1])
                        cylinder(h = prof_gravacao + 3, d = BG_cap_d - 1.2);
                }
        }
    }
}

// ---------------------- PREVIEW DOS BOTOES ---------------------------

module preview_vermelho() {
    color("red", 0.55) {
        translate([0,0,espessura])
            cylinder(h = BV_altura, d1 = BV_cap_d, d2 = BV_anel_d*0.55);
        translate([0,0,-32]) cylinder(h = 32, d = ROSCA_d);
    }
}

module preview_verde() {
    color("green", 0.55) {
        translate([0,0,espessura])
            cylinder(h = BG_flange_h, d = BG_flange_d);
        translate([0,0,espessura + BG_flange_h])
            cylinder(h = BG_altura - BG_flange_h, d1 = BG_cap_d, d2 = 51.9);
        translate([0,0,-BG_barril]) cylinder(h = BG_barril, d = ROSCA_d);
    }
}

tampa();

if (mostrar_botoes) {
    translate([cx_vermelho, cy, 0]) preview_vermelho();
    translate([cx_verde,    cy, 0]) preview_verde();
}

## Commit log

2026-08-15 Refaz a caixa para a Bambu Lab A1 mini com botoes meio embutidos
    Silhueta de 215 x 120 para 178 x 130. Os 215 mm nao cabem na mesa de
    180 x 180 em nenhuma orientacao: a 45 graus um retangulo 215 x 120 pede
    236,8 mm. Mantendo os dois botoes no mesmo eixo, a folga entre as capas
    cai de 25,35 para 4,35 mm - nao ha como melhorar, so as duas capas ja
    somam 159,3 mm.
    Cada botao ganha um rebaixo de assento com METADE da altura da capa
    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
    [caixa-corpo.3mf, caixa-corpo.stl, caixa-painel.3mf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]
2026-08-20 Adiciona berco do interruptor SS12D00G4 na parede de tras do corpo
    O corpo ganhou uma estacao para a chave deslizante SS12D00G4 em
    y = 130, eixo da haste em x = 69,50 e z = 12,00. E uma bolsa
    12,20 x 4,60 x 5,50 cercada de plastico nos quatro lados, aberta para
    dentro da caixa, com rasgo de 6,00 x 3,00 por onde a haste sai deixando
    2,00 mm para fora. Prende com cola quente, sem parafuso.
    POSICAO. O pedido apontou a parede pelo eixo do botao vermelho, x = 56.
    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
    [caixa-corpo.3mf, caixa-corpo.stl, caixa-painel.3mf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]
2026-08-24 Acrescenta perna e degrau_da_perna - secoes do pino fendido
    O brief original dava a cada secao a sua propria corda, sem vertice
    compartilhado entre secoes de raio diferente empilhadas no mesmo pino - a
    secao larga saia com uma aresta unica ali onde a estreita tem tres, e
    'conferir' acusaria aresta fora de 2 triangulos por falta de vertice
    comum. As duas funcoes ganham 'ys', a lista de |y| onde inserir vertices
    extras na corda; quem monta o pino passa a MESMA lista a todas as secoes,
    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
2026-08-24 Fix round 1: degrau_da_perna reusa _corda, teste exercita 2+ pontos internos
    _corda tinha a formula da corda do pino duplicada em degrau_da_perna, porque
    a lista concatenada de _corda nao servia ali - o arco interno entra entre os
    dois trechos. _corda passa a devolver os dois trechos separados, e os dois
    consumidores (perna e degrau_da_perna) os intercalam como precisam; y_min
    deixa de ser parametro morto.
    test_degrau_da_perna_fecha_um_solido usava so dois raios, entao nenhuma
    corda tinha mais de um vertice interno e a ordem relativa entre eles (a
    parte que reversed(e) + e garante) nunca era exercitada. Troca para os
    cinco raios do pino real, com pares que forcam ate 4 vertices extras numa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
2026-08-24 Reescreve parametros e conferir_projeto para PLA, KCD1 e perfboard
2026-08-24 Restaura a conferencia de material sob a cabeca do parafuso da tampa
2026-08-24 Funde painel e corpo numa peca so, com alivio de boca nos furos
2026-08-24 Abre a estacao da chave KCD1 na parede de tras com face_vertical e tubo
2026-08-24 Acrescenta os 4 pinos farpados da perfboard na tampa
    tampa() ganha o perfil de pino em D (ombro, haste, farpa, guias
    escalonadas), fendido ao meio via M.perna/M.degrau_da_perna com a
    lista ys compartilhada entre todas as secoes do mesmo pino - sem
    ela a secao larga teria uma aresta unica onde a estreita tem tres,
    e a malha abriria na junta em T. z=0 passa a ser a face externa
    (rebaixo dos parafusos); os pinos crescem de TAMPA_ESP para cima.
2026-08-24 Apaga costura do nucleo e atualiza validar_modelo para as 2 pecas
2026-08-24 Refaz as pranchas para as 2 pecas e a estacao da chave KCD1
    CX-01 aposentada: o painel deixou de ser peca. CX-02 passa a ser a peca
    fundida, CX-03 ganha o detalhe do pino da perfboard, e a CX-04 troca o
    berco da SS12D00G4 pela estacao da chave gangorra.
    A medicao do corpo deixou de usar 'camadas'. Ela indexa camadas por
    posicao supondo peca prismatica, e o circulo do rebaixo da chave poe 54
    alturas distintas na malha - os indices passavam a apontar para o lugar
    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
2026-08-24 Atualiza README e lista de materiais para PLA, 2 pecas e KCD1
    Apaga os artefatos das pecas que sumiram: caixa-painel.3mf/.stl,
    desenho-caixa-painel.svg e desenho-caixa-berco.svg.
    Corrige na spec os numeros que a implementacao mudou: rebaixo da chave
    D26 -> D25 (com D26 ele ficava a 1,80 mm da coluna central, abaixo do
    minimo de 2,00 da propria conferencia), furo D20,40 -> D20,20 (dimensionado
    sobre o corpo real D19,80, nao sobre o D20,00 nominal do recorte), as duas
    pontes que decorrem disso, e os volumes, que passam de estimativa a medida.
    Sinaliza que a calibracao do furo M24 foi feita em PETG e nao transfere
    para PLA - fora do caminho critico, porque o furo do barril vem da
    especificaca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
    [caixa-corpo.3mf, caixa-corpo.stl, caixa-painel.3mf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]
2026-08-24 Regenera os .3mf com o modelo final
    [caixa-corpo.3mf, caixa-tampa.3mf]
2026-08-24 Corrige o Critical e os achados de documentacao da revisao final
    C1: a secao 1 da lista de materiais era a revisao anterior intacta - mandava
    imprimir um corpo de prova de rebaixos D99,30/D61,60 que nao existem e dizia
    que o botao verde aperta 11,00 mm de painel, quando a peca oferece 8,00 nos
    dois. Era o pior defeito da entrega: o unico documento cuja funcao e ser
    seguido antes de comprar e imprimir.
    I7: procedimento de inserto justificava a temperatura pelo PETG (220-240) -
    PLA amolece antes, 200-220.
    I8: bloco de mesa ainda era da placa de 209,30x108,50 na K1C, contradizendo a
    tabela PLA/A1 mini 30 linhas acima.
    I9: estimativa de filamento era 50 %% do volume ANTIGO (223 cm3); o certo e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
2026-08-24 Corrige os 6 achados Important das pranchas
    I1 cota que mentia: o vao saia do assento da tampa (28 mm desenhados) sob um
    texto de 35,00. Agora sai da face dos botoes, que e de onde z e medido -
    conferido no SVG: 35,00 mm desenhados.
    I2 a chave saia em linha CHEIA na vista frontal, que mostra a parede da
    FRENTE. Ela esta na de tras: e feicao oculta e vai inteira em tracejado. O
    x nao espelha, e a docstring que dizia o contrario foi reescrita.
    I3 o detalhe da coluna dizia 'furo nas DUAS pontas', contradizendo a nota 2
    da mesma prancha e a malha.
    I4 a sonda do pino era morta e CEGA: nunca usada, e analisar() devolvia zero
    furos em toda altura porque a secao da perna e um D e e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
    [caixa-corpo.3mf, caixa-tampa.3mf]
2026-08-24 Fecha os Minor da revisao final
    O mais grave era de propagacao, nao de decisao: os rulings C11 e C12 mudaram
    o projeto e a spec ficou na versao antiga - secao 8 regra 5 dizia Rebaixo D26
    onde o codigo diz D25, e as regras 11 e 12 descreviam a conferencia que
    reprovava por construcao. A spec e a autoridade, entao a divergencia era dela
    para com o codigo, nao o contrario.
    Tambem: a secao 3.5 afirmava que a folga de 5,50 mm sob o botao verde e
    'vigiada pela regra 12' - falso. O verde desvia no PLANO com 3,15 mm, e a
    regra se da por satisfeita antes de olhar o z. Corrigido com a explicacao de
    como a regra realmente segura.
    Codigo: docstring de medir_chave creditava o filtro de y com uma rejeic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
    [caixa-corpo.3mf, caixa-tampa.3mf]
2026-08-25 Gira as pranchas para A2 retrato e confere o layout no SVG emitido
    As tres pranchas saiam em A2 paisagem com as vistas a esquerda e uma coluna
    de texto fixa em x = 330. As ampliacoes cresciam para a direita a partir de
    origens fixas e entravam na coluna: o detalhe do alivio de boca, ampliado 8x,
    tem 220 mm de papel - um furo de barril M24 ampliado 8x da 202 mm sozinho - e
    imprimia por cima das notas de fabricacao.
    Em retrato (420 x 594) vistas e ampliacoes ficam na metade de cima e o texto
    na de baixo, com a largura inteira da folha. O detalhe do alivio passou a 4:1
    para caber ao lado da vista superior; a 4:1 o rebaixo de 0,50 ainda sai com
    2 mm, e o que o detalhe precisa mostrar e que ele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
2026-09-24 Spec: entrada USB-C do TP4056 na tampa, sem os pinos da perfboard
    So a tampa muda; o corpo ja impresso nao pode mudar um vertice, e o plano
    confere isso por hash da malha. O modulo fica em pe na borda direita porque o
    USB-C e paralelo a placa e o plugue entra de baixo para cima. Registra que o
    modelo da tampa e o reflexo da peca fisica, e que ela passa a ter lado certo.
2026-09-24 Plano de implementacao da tampa do TP4056
    Oito tarefas. As regras, as sondas e a malha nova foram prototipadas antes:
    a tampa fecha em 1e-9 com 81,97 cm3, cada perturbacao dispara a sua regra e
    cada mutacao de malha e acusada. Corrige na spec o fundo do rebaixo (2,00, nao
    1,60), a altura da sonda da janela, e registra que a planta do berco fica na
    vista 1:1.
2026-09-24 Acrescenta as 9 regras de projeto do berco do TP4056
2026-09-24 Remove do nucleo as primitivas que so os pinos usavam
2026-09-24 Normaliza as quebras de linha do test_projeto.py
2026-09-24 Troca as sondas do pino pelas do berco, com teste de mutacao
2026-09-24 Documenta a tampa do TP4056 e regrava a tampa
    [caixa-tampa.3mf, caixa-tampa.stl]
2026-09-24 Troca o material do selo das pranchas de PETG para PLA
2026-09-24 Troca o material do cabecalho dos STL dos gabaritos de PETG para PLA
    [gabarito-passante.stl, gabarito-roscado.stl]
